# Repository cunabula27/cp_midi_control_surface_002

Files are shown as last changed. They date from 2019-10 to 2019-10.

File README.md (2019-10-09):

# midi_control_surface_002
Midi Control Surface for Arduino Mega 2560 Rev3 running custom OpenDeck firmware available from www.shanteacontrols.com

Well, it's really version 2.1 - I pretty much finished version 2 but made a few rookie errors. Easier to start again with a clean project file.

Once again didn't start on GitHub so no easy way for me to roll the work back #lesigh

I'm learning, just very slowly.

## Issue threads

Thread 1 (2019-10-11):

Potentiometers run backwards

cunabula27, 2019-10-11:
All rotary potentiometers in the prototype boards have reversed polarity so output midi ID 127 at full left and midi ID 0 at full right.

Easily fixed in software using the Configurator and setting the control to Inverted but would be better to fix on the board.

cunabula27, 2019-10-11:
Pin 3 is VCC and Pin 1 is GND on Alps RK09K/RK09D series potentiometers see https://docs-emea.rs-online.com/webdocs/0f4c/0900766b80f4c571.pdf

Closed 2019-10-11.

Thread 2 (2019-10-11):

LED graphics (Presets)

cunabula27, 2019-10-11:
Main board graphics have the number of Presets as 6 - this is the maximum that OpenDeck can have on an Arduino Mega2560. However this project uses the mega6mux target which onlly allows for three presets - it has a lot more available physical controls, there's only so much space on the Arduino's memory.

Adjust board graphics accordingly (or leave blank).

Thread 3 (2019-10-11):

Component graphics (potentiometers)

cunabula27, 2019-10-11:
Having the panel graphics as part of the component footprint works well.

Currently using different potentiometers (same pin placement but wider angle of travel).

Create new footprint to accomodate this.

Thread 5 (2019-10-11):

Library files not correctly linked

cunabula27, 2019-10-11:
Current linking of library files for the project isn't right - rescue.lib is required.

Fix it.

cunabula27, 2019-10-11:
Appears to be a problem with using absolute paths rather than relative ones.

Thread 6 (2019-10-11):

Pin 3 is VCC and Pin 1 is GND on Alps RK09K/RK09D series potentiometers see https://docs-emea.rs-online.com/webdocs/0f4c/0900766b80f4c571.pdf

cunabula27, 2019-10-11:
Pin 3 is VCC and Pin 1 is GND on Alps RK09K/RK09D series potentiometers see https://docs-emea.rs-online.com/webdocs/0f4c/0900766b80f4c571.pdf

_Originally posted by @cunabula27 in https://github.com/cunabula27/cp_midi_control_surface_002/issues/1#issuecomment-541006642_

Reverse symbols in schematic and correctly connect components on board to reflect this.

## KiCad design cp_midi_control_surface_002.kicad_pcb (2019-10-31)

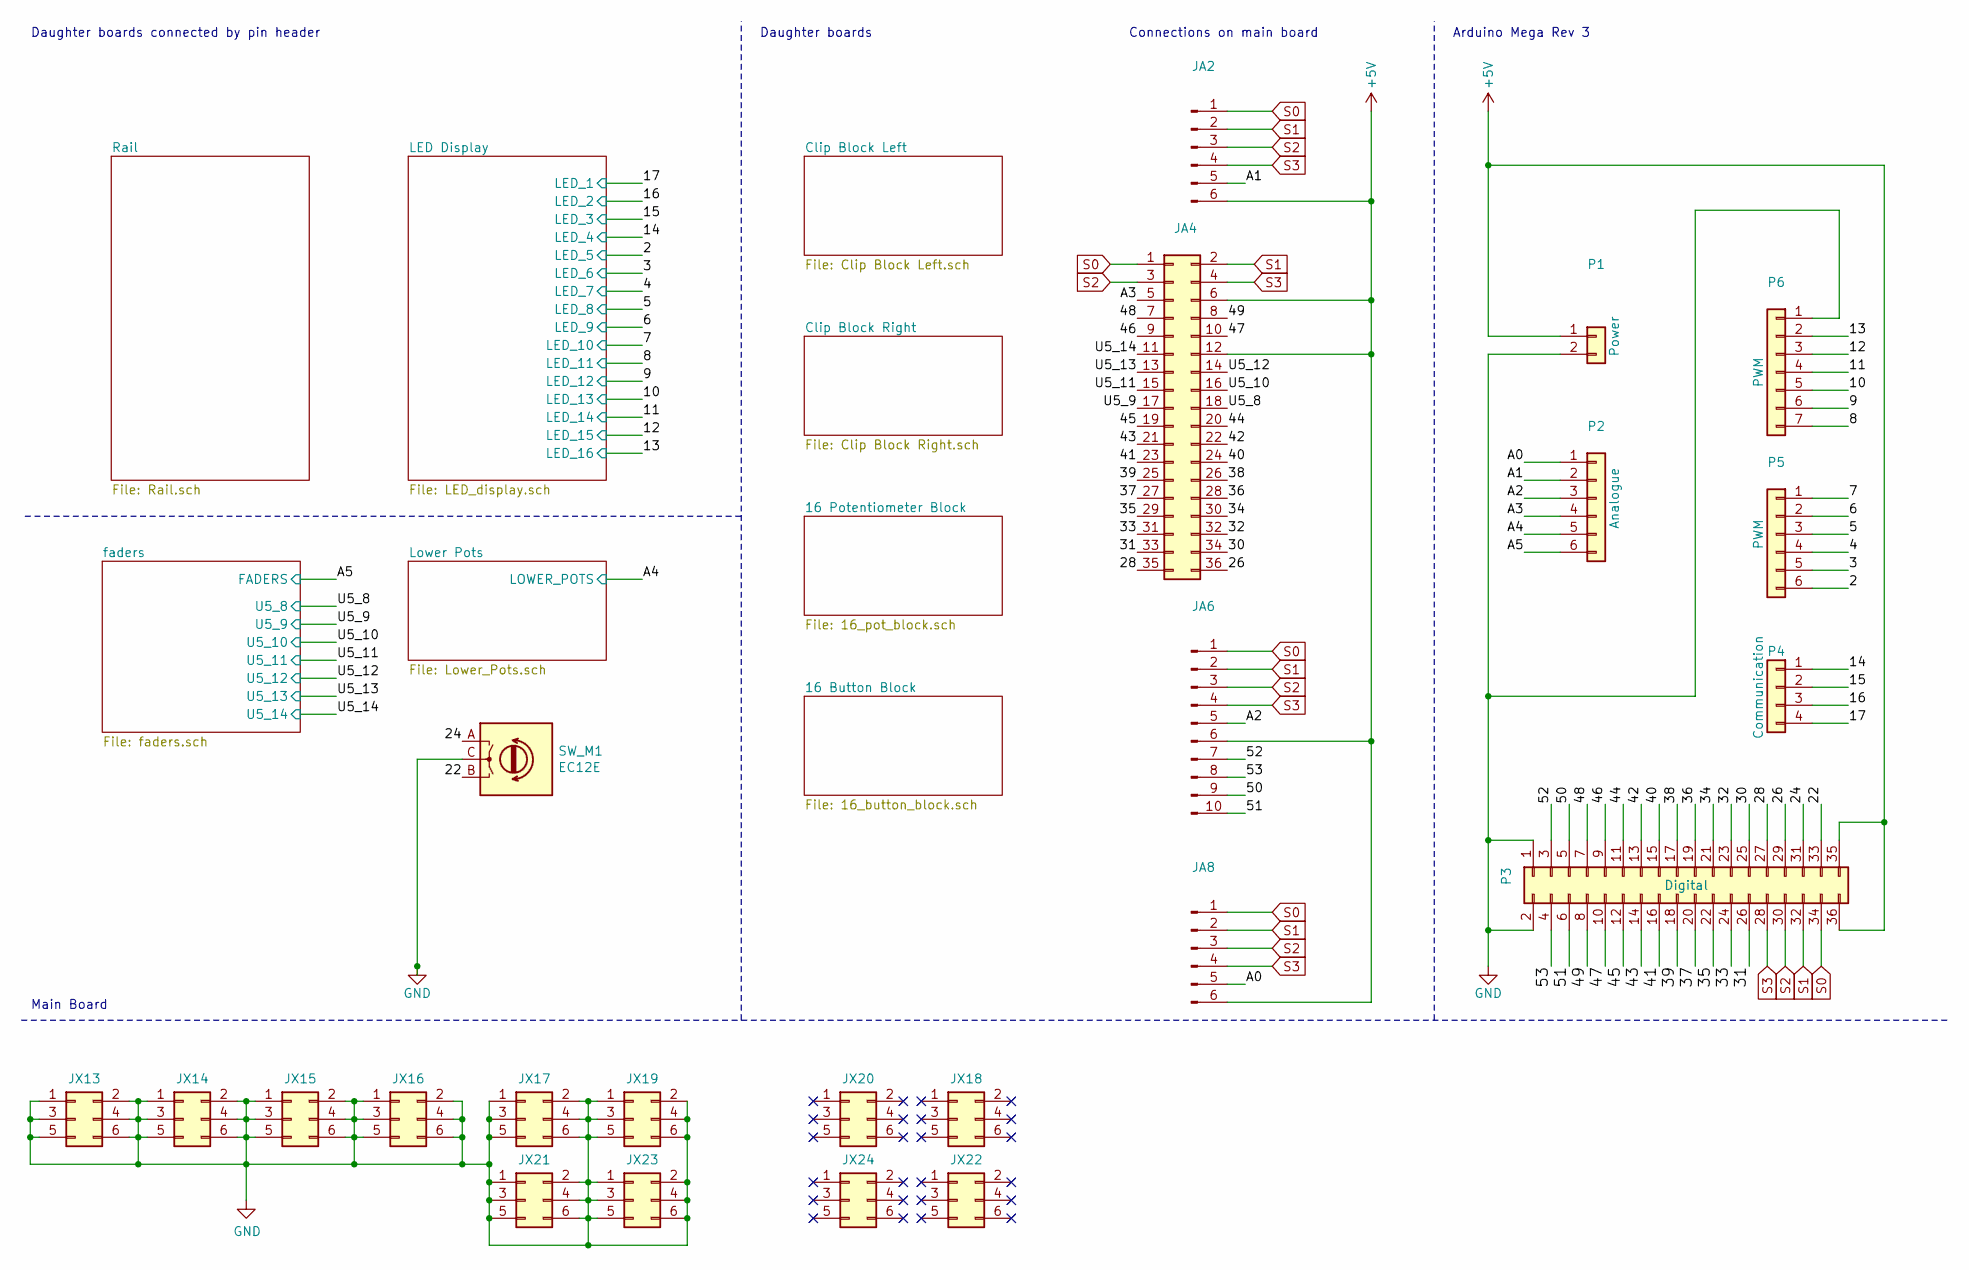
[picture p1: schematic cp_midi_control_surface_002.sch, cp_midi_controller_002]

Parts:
JA2, JA8: PinHeader_2x03_P2.54mm_Vertical
JA4: PinHeader_2x18_P2.54mm_Vertical
JA6: PinHeader_2x05_P2.54mm_Vertical
JX13, JX14, JX15, JX16, JX17, JX18, JX19, JX20, JX21, JX22, JX23, JX24: Conn_02x03_Odd_Even; PinHeader_2x03_P2.54mm_Vertical
P1: Power; PinHeader_1x02_P2.54mm_Vertical
P2: Analogue; PinHeader_1x06_P2.54mm_Vertical
P3: Digital; PinHeader_2x18_P2.54mm_Vertical
P4: Communication; PinHeader_1x04_P2.54mm_Vertical
P5: PWM; PinHeader_1x06_P2.54mm_Vertical
P6: PWM; PinHeader_1x07_P2.54mm_Vertical
SW_M1: EC12E; RotaryEncoder_Alps_EC12E_Vertical_H20mm_6_Preset_Silk_EDIT

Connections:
+5V: JA2.6, JA4.6, JA4.12, JA6.6, JA8.6, P1.1, P3.35, P3.36; also elsewhere on the board
/2: P5.6; also elsewhere on the board
/3: P5.5; also elsewhere on the board
/4: P5.4; also elsewhere on the board
/5: P5.3; also elsewhere on the board
/6: P5.2; also elsewhere on the board
/7: P5.1; also elsewhere on the board
/8: P6.7; also elsewhere on the board
/9: P6.6; also elsewhere on the board
/10: P6.5; also elsewhere on the board
/11: P6.4; also elsewhere on the board
/12: P6.3; also elsewhere on the board
/13: P6.2; also elsewhere on the board
/14: P4.1; also elsewhere on the board
/15: P4.2; also elsewhere on the board
/16: P4.3; also elsewhere on the board
/17: P4.4; also elsewhere on the board
/22: P3.33, SW_M1.B
/24: P3.31, SW_M1.A
/26: JA4.36, P3.29
/28: JA4.35, P3.27
/30: JA4.34, P3.25
/31: JA4.33, P3.26
/32: JA4.32, P3.23
/33: JA4.31, P3.24
/34: JA4.30, P3.21
/35: JA4.29, P3.22
/36: JA4.28, P3.19
/37: JA4.27, P3.20
/38: JA4.26, P3.17
/39: JA4.25, P3.18
/40: JA4.24, P3.15
/41: JA4.23, P3.16
/42: JA4.22, P3.13
/43: JA4.21, P3.14
/44: JA4.20, P3.11
/45: JA4.19, P3.12
/46: JA4.9, P3.9
/47: JA4.10, P3.10
/48: JA4.7, P3.7
/49: JA4.8, P3.8
/50: JA6.9, P3.5
/51: JA6.10, P3.6
/52: JA6.7, P3.3
/53: JA6.8, P3.4
/A0: JA8.5, P2.1
/A1: JA2.5, P2.2
/A2: JA6.5, P2.3
/A3: JA4.5, P2.4
/A4: P2.5; also elsewhere on the board
/A5: P2.6; also elsewhere on the board
/U5_8: JA4.18; also elsewhere on the board
/U5_9: JA4.17; also elsewhere on the board
/U5_10: JA4.16; also elsewhere on the board
/U5_11: JA4.15; also elsewhere on the board
/U5_12: JA4.14; also elsewhere on the board
/U5_13: JA4.13; also elsewhere on the board
/U5_14: JA4.11; also elsewhere on the board
GND: JX13.1, JX13.2, JX13.3, JX13.4, JX13.5, JX13.6, JX14.1, JX14.2, JX14.3, JX14.4, JX14.5, JX14.6, JX15.1, JX15.2, JX15.3, JX15.4, JX15.5, JX15.6, JX16.1, JX16.2, JX16.3, JX16.4, JX16.5, JX16.6, JX17.1, JX17.2, JX17.3, JX17.4, JX17.5, JX17.6, JX19.1, JX19.2, JX19.3, JX19.4, JX19.5, JX19.6, JX21.1, JX21.2, JX21.3, JX21.4, JX21.5, JX21.6, JX23.1, JX23.2, JX23.3, JX23.4, JX23.5, JX23.6, P1.2, P3.1, P3.2, P6.1, SW_M1.C; also elsewhere on the board
S0: JA2.1, JA4.1, JA6.1, JA8.1, P3.34; also elsewhere on the board
S1: JA2.2, JA4.2, JA6.2, JA8.2, P3.32; also elsewhere on the board
S2: JA2.3, JA4.3, JA6.3, JA8.3, P3.30; also elsewhere on the board
S3: JA2.4, JA4.4, JA6.4, JA8.4, P3.28; also elsewhere on the board

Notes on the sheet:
Arduino Mega Rev 3
Daughter boards
Daughter boards connected by pin header
Main Board
Connections on main board

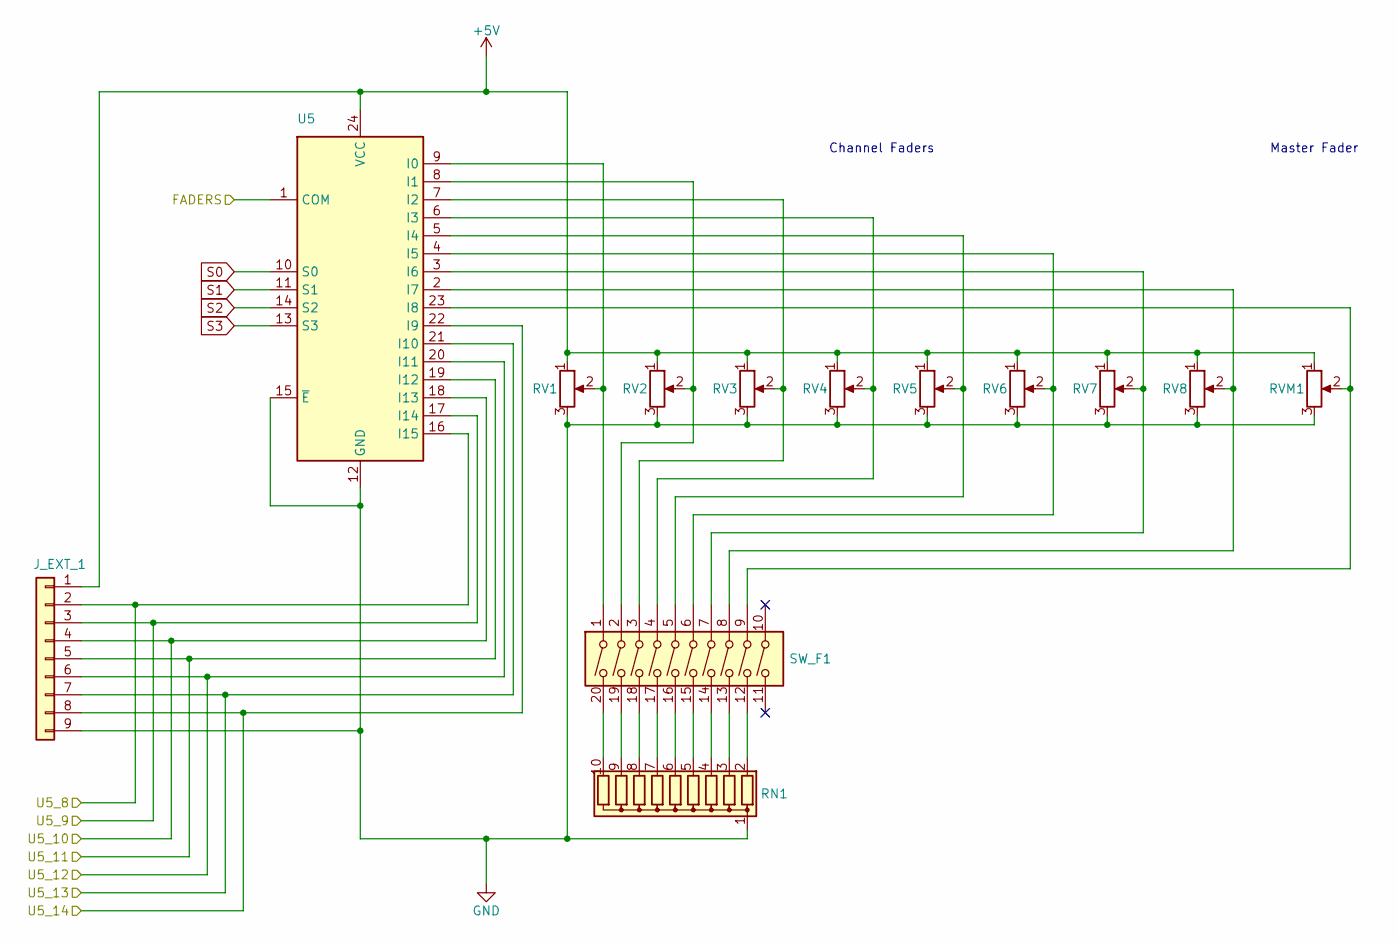
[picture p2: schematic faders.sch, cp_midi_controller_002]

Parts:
J_EXT_1: Conn_01x10; PinSocket_1x09_P2.54mm_Vertical
RN1: 2.2K (Bussed); R_Array_SIP10
RV1, RV2, RV3, RV4, RV5, RV6, RV7, RV8: PTA4543; Potentiometer_Bourns_PTA4543_Single_Slide_CP_EDIT
RVM1: PTA4543; Potentiometer_Bourns_PTA4543_Single_Slide_CP_EDIT
SW_F1: SW_DIP_x10; DIP-20_W7.62mm
U5: CD74HC4067M; SOIC-24W_7.5x15.4mm_P1.27mm

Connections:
+5V: J_EXT_1.1, RV1.1, RV2.1, RV3.1, RV4.1, RV5.1, RV6.1, RV7.1, RV8.1, RVM1.1, U5.24 (VCC); also elsewhere on the board
/A5: U5.1 (COM); also elsewhere on the board
/U5_8: J_EXT_1.2, U5.16 (I15); also elsewhere on the board
/U5_9: J_EXT_1.3, U5.17 (I14); also elsewhere on the board
/U5_10: J_EXT_1.4, U5.18 (I13); also elsewhere on the board
/U5_11: J_EXT_1.5, U5.19 (I12); also elsewhere on the board
/U5_12: J_EXT_1.6, U5.20 (I11); also elsewhere on the board
/U5_13: J_EXT_1.7, U5.21 (I10); also elsewhere on the board
/U5_14: J_EXT_1.8, U5.22 (I9); also elsewhere on the board
GND: J_EXT_1.9, RN1.1 (common), RV1.3, RV2.3, RV3.3, RV4.3, RV5.3, RV6.3, RV7.3, RV8.3, RVM1.3, U5.12 (GND), U5.15 (~E); also elsewhere on the board
unnamed: RN1.2 (R1), SW_F1.12
unnamed: RN1.3 (R2), SW_F1.13
unnamed: RN1.4 (R3), SW_F1.14
unnamed: RN1.5 (R4), SW_F1.15
unnamed: RN1.6 (R5), SW_F1.16
unnamed: RN1.7 (R6), SW_F1.17
unnamed: RN1.8 (R7), SW_F1.18
unnamed: RN1.9 (R8), SW_F1.19
unnamed: RN1.10 (R9), SW_F1.20
unnamed: RV1.2, SW_F1.1, U5.9 (I0)
unnamed: RV2.2, SW_F1.2, U5.8 (I1)
unnamed: RV3.2, SW_F1.3, U5.7 (I2)
unnamed: RV4.2, SW_F1.4, U5.6 (I3)
unnamed: RV5.2, SW_F1.5, U5.5 (I4)
unnamed: RV6.2, SW_F1.6, U5.4 (I5)
unnamed: RV7.2, SW_F1.7, U5.3 (I6)
unnamed: RV8.2, SW_F1.8, U5.2 (I7)
unnamed: RVM1.2, SW_F1.9, U5.23 (I8)
S0: U5.10 (S0); also elsewhere on the board
S1: U5.11 (S1); also elsewhere on the board
S2: U5.14 (S2); also elsewhere on the board
S3: U5.13 (S3); also elsewhere on the board

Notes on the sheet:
Channel Faders
Master Fader

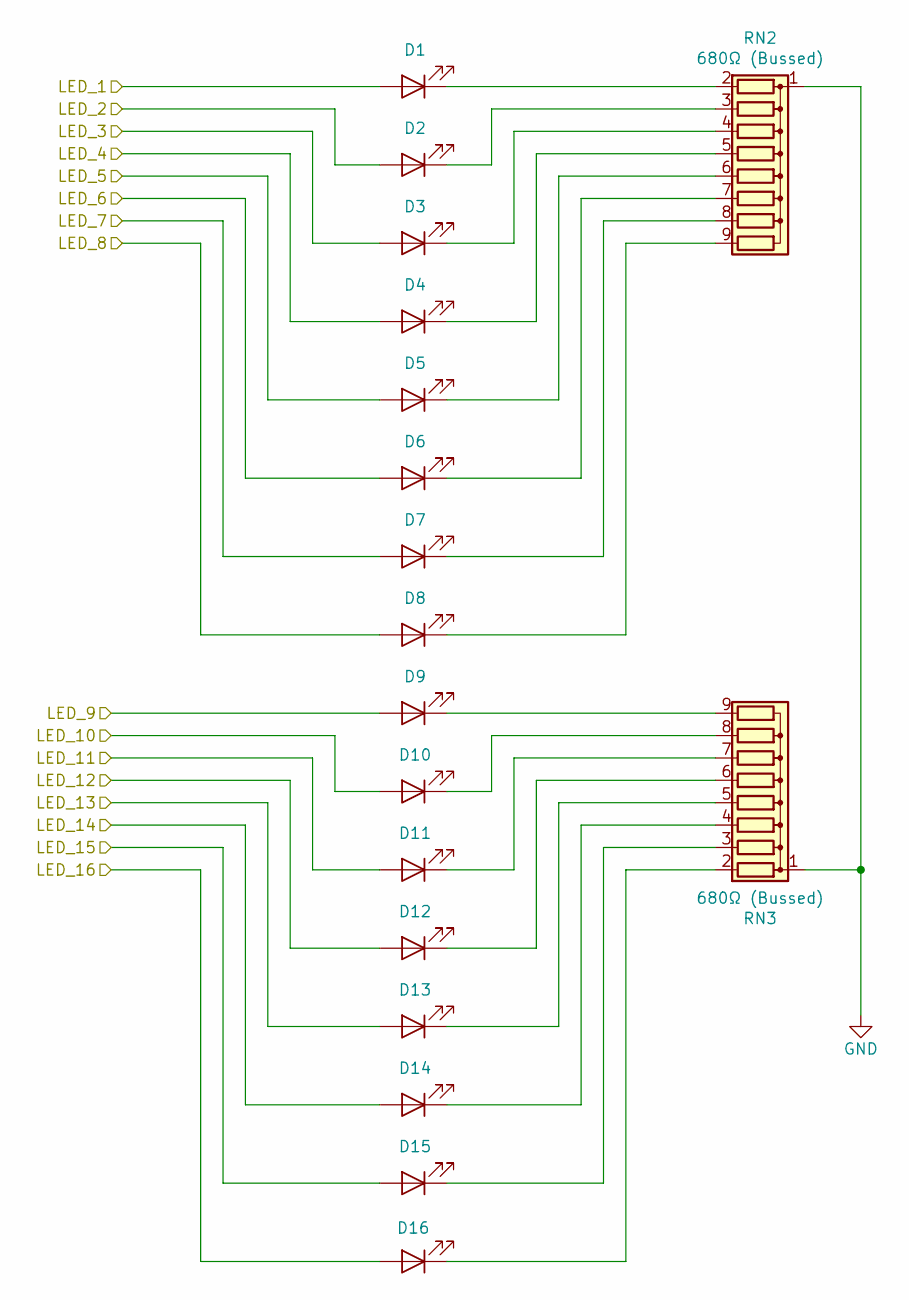
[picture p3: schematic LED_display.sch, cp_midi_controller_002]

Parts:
D1, D2, D3, D4, D5, D6, D7, D8, D9, D10, D11, D12, D13, D14, D15, D16: LED; LED_D3.0mm_EDIT
RN2, RN3: 680Ω (Bussed); R_Array_SIP9

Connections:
/2: D5.2 (A); also elsewhere on the board
/3: D6.2 (A); also elsewhere on the board
/4: D7.2 (A); also elsewhere on the board
/5: D8.2 (A); also elsewhere on the board
/6: D9.2 (A); also elsewhere on the board
/7: D10.2 (A); also elsewhere on the board
/8: D11.2 (A); also elsewhere on the board
/9: D12.2 (A); also elsewhere on the board
/10: D13.2 (A); also elsewhere on the board
/11: D14.2 (A); also elsewhere on the board
/12: D15.2 (A); also elsewhere on the board
/13: D16.2 (A); also elsewhere on the board
/14: D4.2 (A); also elsewhere on the board
/15: D3.2 (A); also elsewhere on the board
/16: D2.2 (A); also elsewhere on the board
/17: D1.2 (A); also elsewhere on the board
GND: RN2.1 (common), RN3.1 (common); also elsewhere on the board
unnamed: D1.1 (K), RN2.2 (R1)
unnamed: D2.1 (K), RN2.3 (R2)
unnamed: D3.1 (K), RN2.4 (R3)
unnamed: D4.1 (K), RN2.5 (R4)
unnamed: D5.1 (K), RN2.6 (R5)
unnamed: D6.1 (K), RN2.7 (R6)
unnamed: D7.1 (K), RN2.8 (R7)
unnamed: D8.1 (K), RN2.9 (R8)
unnamed: D9.1 (K), RN3.9 (R8)
unnamed: D10.1 (K), RN3.8 (R7)
unnamed: D11.1 (K), RN3.7 (R6)
unnamed: D12.1 (K), RN3.6 (R5)
unnamed: D13.1 (K), RN3.5 (R4)
unnamed: D14.1 (K), RN3.4 (R3)
unnamed: D15.1 (K), RN3.3 (R2)
unnamed: D16.1 (K), RN3.2 (R1)

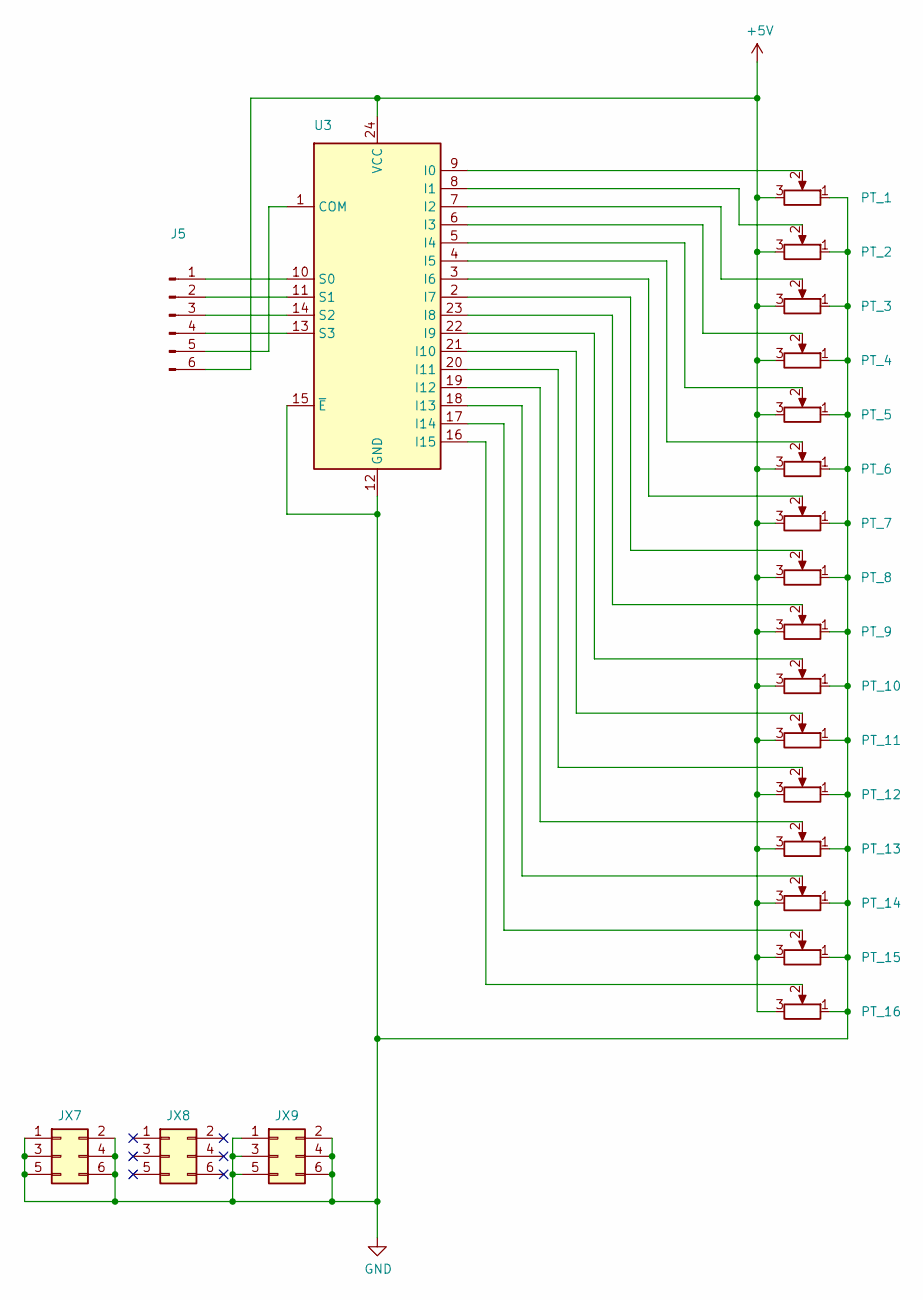
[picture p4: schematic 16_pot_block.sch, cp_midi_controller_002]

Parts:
J5: PinHeader_2x03_P2.54mm_Vertical
JX7, JX8, JX9: Conn_02x03_Odd_Even; PinHeader_2x03_P2.54mm_Vertical
PT_1, PT_2, PT_3, PT_4, PT_5, PT_6, PT_7, PT_8, PT_9, PT_10, PT_11, PT_12, PT_13, PT_14, PT_15, PT_16: 10k; Potentiometer_Alps_RK09D1130X
U3: CD74HC4067M; SOIC-24W_7.5x15.4mm_P1.27mm

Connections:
+5V: J5.6, PT_1.3, PT_2.3, PT_3.3, PT_4.3, PT_5.3, PT_6.3, PT_7.3, PT_8.3, PT_9.3, PT_10.3, PT_11.3, PT_12.3, PT_13.3, PT_14.3, PT_15.3, PT_16.3, U3.24 (VCC); also elsewhere on the board
GND: JX7.1, JX7.2, JX7.3, JX7.4, JX7.5, JX7.6, JX9.1, JX9.2, JX9.3, JX9.4, JX9.5, JX9.6, PT_1.1, PT_2.1, PT_3.1, PT_4.1, PT_5.1, PT_6.1, PT_7.1, PT_8.1, PT_9.1, PT_10.1, PT_11.1, PT_12.1, PT_13.1, PT_14.1, PT_15.1, PT_16.1, U3.12 (GND), U3.15 (~E); also elsewhere on the board
unnamed: J5.1, U3.10 (S0)
unnamed: J5.2, U3.11 (S1)
unnamed: J5.3, U3.14 (S2)
unnamed: J5.4, U3.13 (S3)
unnamed: J5.5, U3.1 (COM)
unnamed: PT_1.2, U3.9 (I0)
unnamed: PT_2.2, U3.8 (I1)
unnamed: PT_3.2, U3.7 (I2)
unnamed: PT_4.2, U3.6 (I3)
unnamed: PT_5.2, U3.5 (I4)
unnamed: PT_6.2, U3.4 (I5)
unnamed: PT_7.2, U3.3 (I6)
unnamed: PT_8.2, U3.2 (I7)
unnamed: PT_9.2, U3.23 (I8)
unnamed: PT_10.2, U3.22 (I9)
unnamed: PT_11.2, U3.21 (I10)
unnamed: PT_12.2, U3.20 (I11)
unnamed: PT_13.2, U3.19 (I12)
unnamed: PT_14.2, U3.18 (I13)
unnamed: PT_15.2, U3.17 (I14)
unnamed: PT_16.2, U3.16 (I15)

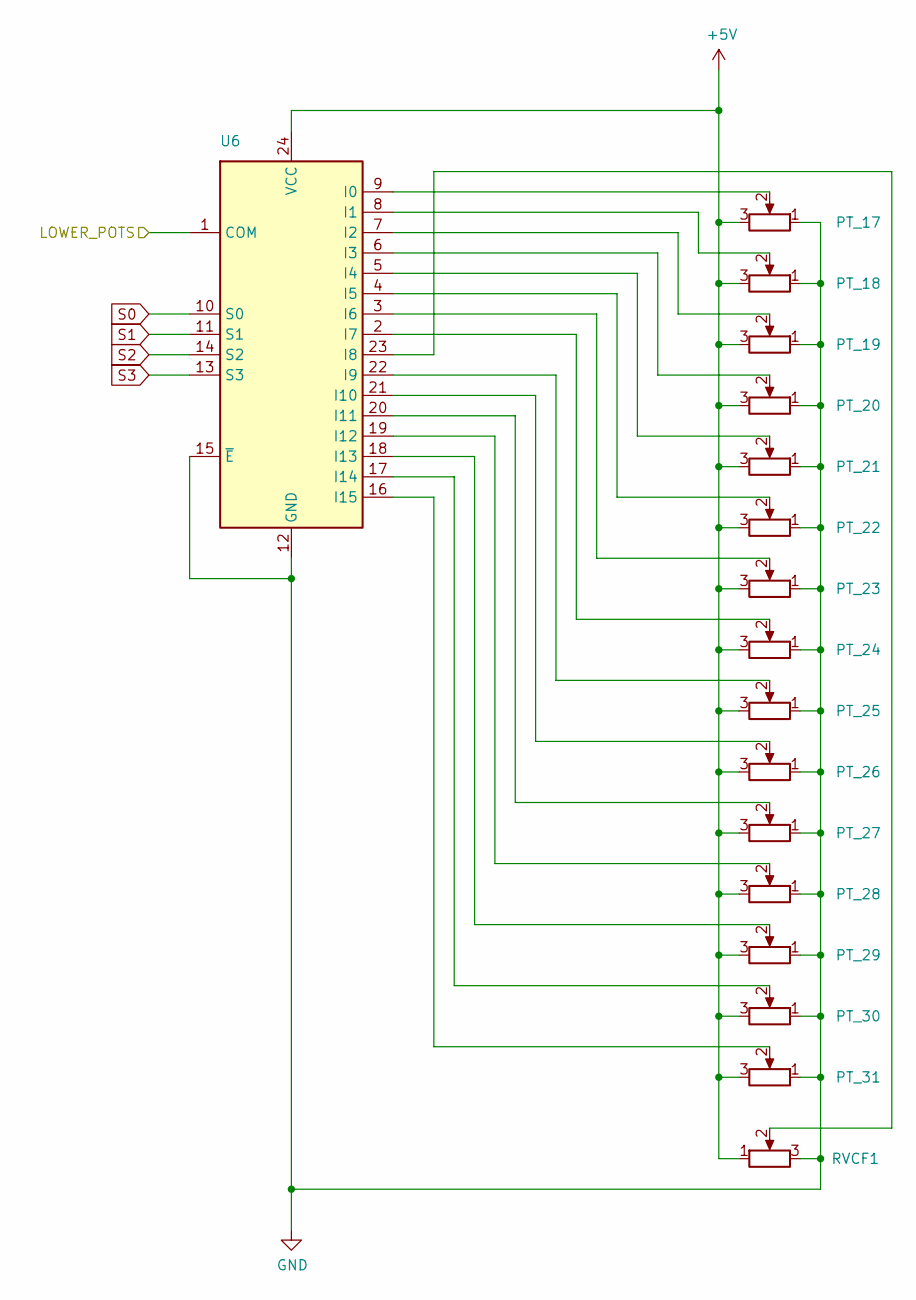
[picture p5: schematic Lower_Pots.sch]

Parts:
PT_17, PT_18, PT_19, PT_20, PT_21, PT_22, PT_23, PT_24, PT_25, PT_26, PT_27, PT_28, PT_29, PT_30, PT_31: 10k; Potentiometer_Alps_RK09D1130X
RVCF1: PTA4543; Potentiometer_Bourns_PTA4543_Single_Slide_CP_EDIT
U6: CD74HC4067M; SOIC-24W_7.5x15.4mm_P1.27mm

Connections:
+5V: PT_17.3, PT_18.3, PT_19.3, PT_20.3, PT_21.3, PT_22.3, PT_23.3, PT_24.3, PT_25.3, PT_26.3, PT_27.3, PT_28.3, PT_29.3, PT_30.3, PT_31.3, RVCF1.1, U6.24 (VCC); also elsewhere on the board
/A4: U6.1 (COM); also elsewhere on the board
GND: PT_17.1, PT_18.1, PT_19.1, PT_20.1, PT_21.1, PT_22.1, PT_23.1, PT_24.1, PT_25.1, PT_26.1, PT_27.1, PT_28.1, PT_29.1, PT_30.1, PT_31.1, RVCF1.3, U6.12 (GND), U6.15 (~E); also elsewhere on the board
unnamed: PT_17.2, U6.9 (I0)
unnamed: PT_18.2, U6.8 (I1)
unnamed: PT_19.2, U6.7 (I2)
unnamed: PT_20.2, U6.6 (I3)
unnamed: PT_21.2, U6.5 (I4)
unnamed: PT_22.2, U6.4 (I5)
unnamed: PT_23.2, U6.3 (I6)
unnamed: PT_24.2, U6.2 (I7)
unnamed: PT_25.2, U6.22 (I9)
unnamed: PT_26.2, U6.21 (I10)
unnamed: PT_27.2, U6.20 (I11)
unnamed: PT_28.2, U6.19 (I12)
unnamed: PT_29.2, U6.18 (I13)
unnamed: PT_30.2, U6.17 (I14)
unnamed: PT_31.2, U6.16 (I15)
unnamed: RVCF1.2, U6.23 (I8)
S0: U6.10 (S0); also elsewhere on the board
S1: U6.11 (S1); also elsewhere on the board
S2: U6.14 (S2); also elsewhere on the board
S3: U6.13 (S3); also elsewhere on the board

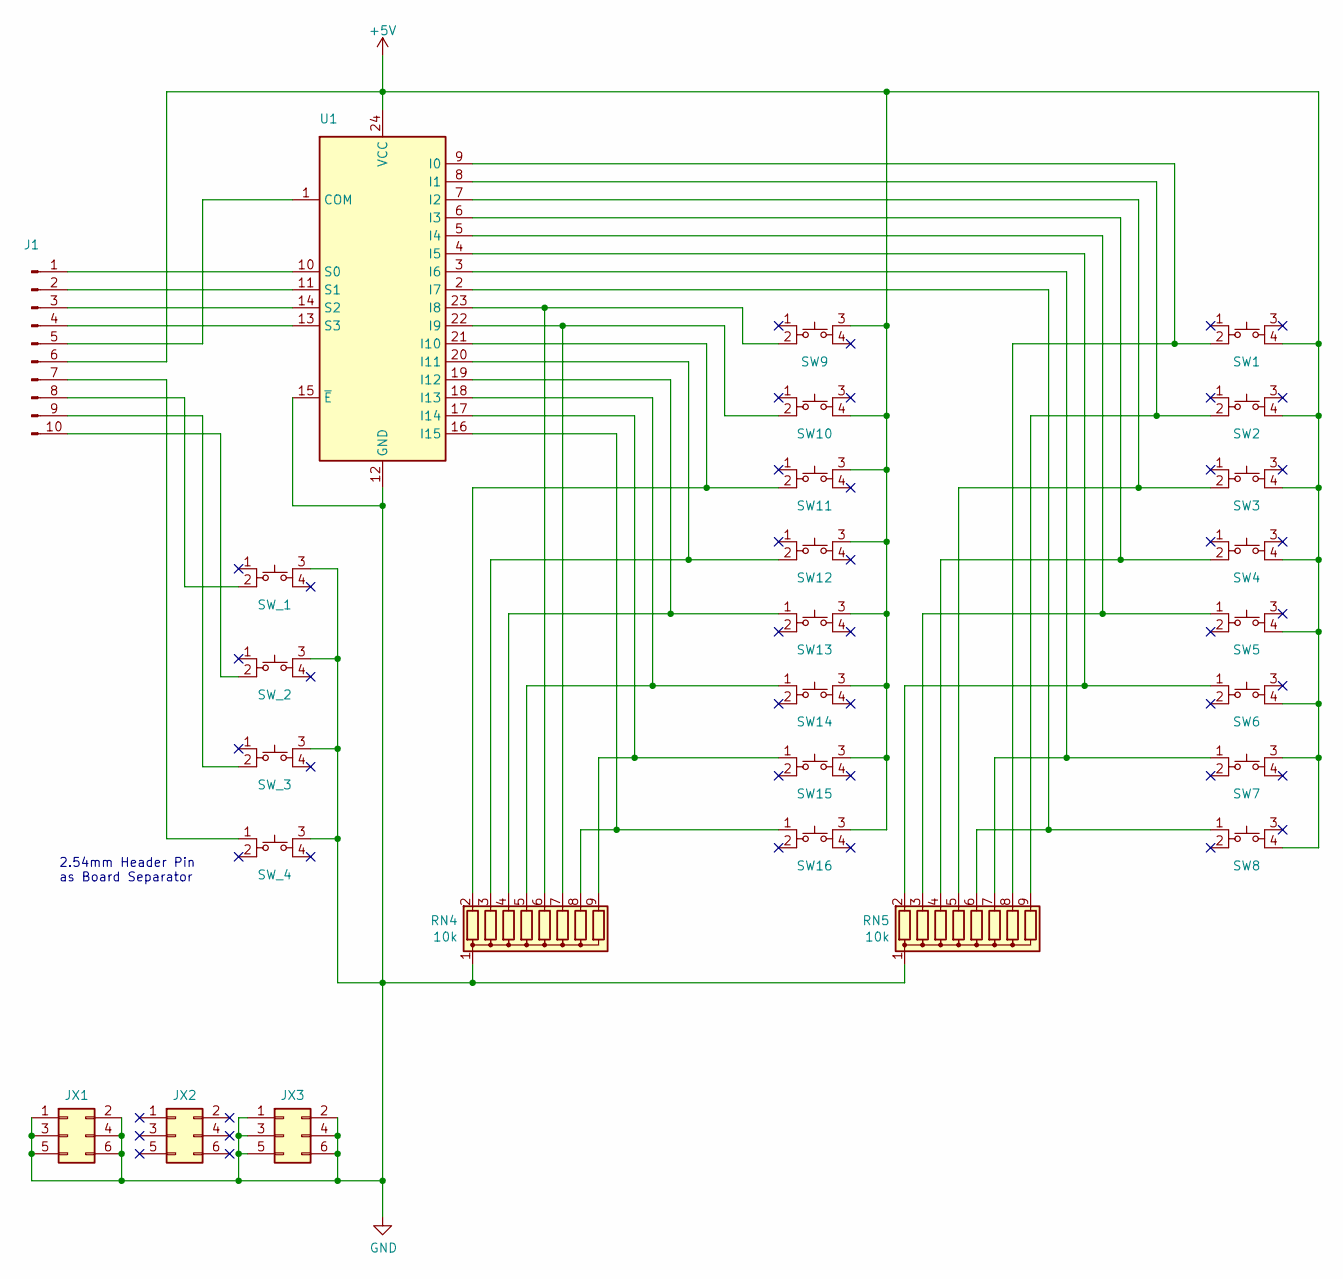
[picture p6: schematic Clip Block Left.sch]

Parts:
J1: Conn_02x05_Odd_Even; PinHeader_2x05_P2.54mm_Vertical
JX1, JX2, JX3: Conn_02x03_Odd_Even; PinHeader_2x03_P2.54mm_Vertical
RN4, RN5: 10k; R_Array_SIP9
SW1, SW2, SW3, SW4, SW5, SW6, SW7, SW8, SW9, SW10, SW11, SW12, SW13, SW14, SW15, SW16: B3F-5050; Omron_B3F-5050
SW_1, SW_2, SW_3, SW_4: B3F-5050; Omron_B3F-5050
U1: CD74HC4067M; SOIC-24W_7.5x15.4mm_P1.27mm

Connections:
+5V: J1.6, SW1.4, SW2.4, SW3.4, SW4.4, SW5.4, SW6.4, SW7.3, SW8.4, SW9.3, SW10.4, SW11.3, SW12.3, SW13.3, SW14.3, SW15.3, SW16.3, U1.24 (VCC); also elsewhere on the board
GND: JX1.1, JX1.2, JX1.3, JX1.4, JX1.5, JX1.6, JX3.1, JX3.2, JX3.3, JX3.4, JX3.5, JX3.6, RN4.1 (common), RN5.1 (common), SW_1.3, SW_2.3, SW_3.3, SW_4.3, U1.12 (GND), U1.15 (~E); also elsewhere on the board
unnamed: J1.1, U1.10 (S0)
unnamed: J1.2, U1.11 (S1)
unnamed: J1.3, U1.14 (S2)
unnamed: J1.4, U1.13 (S3)
unnamed: J1.5, U1.1 (COM)
unnamed: J1.7, SW_4.1 (A)
unnamed: J1.8, SW_1.2
unnamed: J1.9, SW_3.2
unnamed: J1.10, SW_2.2
unnamed: RN4.2 (R1), SW11.2, U1.21 (I10)
unnamed: RN4.3 (R2), SW12.2, U1.20 (I11)
unnamed: RN4.4 (R3), SW13.1 (A), U1.19 (I12)
unnamed: RN4.5 (R4), SW14.1 (A), U1.18 (I13)
unnamed: RN4.6 (R5), SW9.2, U1.23 (I8)
unnamed: RN4.7 (R6), SW10.2, U1.22 (I9)
unnamed: RN4.8 (R7), SW16.1 (A), U1.16 (I15)
unnamed: RN4.9 (R8), SW15.1 (A), U1.17 (I14)
unnamed: RN5.2 (R1), SW6.1 (A), U1.4 (I5)
unnamed: RN5.3 (R2), SW5.1 (A), U1.5 (I4)
unnamed: RN5.4 (R3), SW4.2, U1.6 (I3)
unnamed: RN5.5 (R4), SW3.2, U1.7 (I2)
unnamed: RN5.6 (R5), SW8.1 (A), U1.2 (I7)
unnamed: RN5.7 (R6), SW7.1 (A), U1.3 (I6)
unnamed: RN5.8 (R7), SW1.2, U1.9 (I0)
unnamed: RN5.9 (R8), SW2.2, U1.8 (I1)

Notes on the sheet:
2.54mm Header Pin as Board Separator

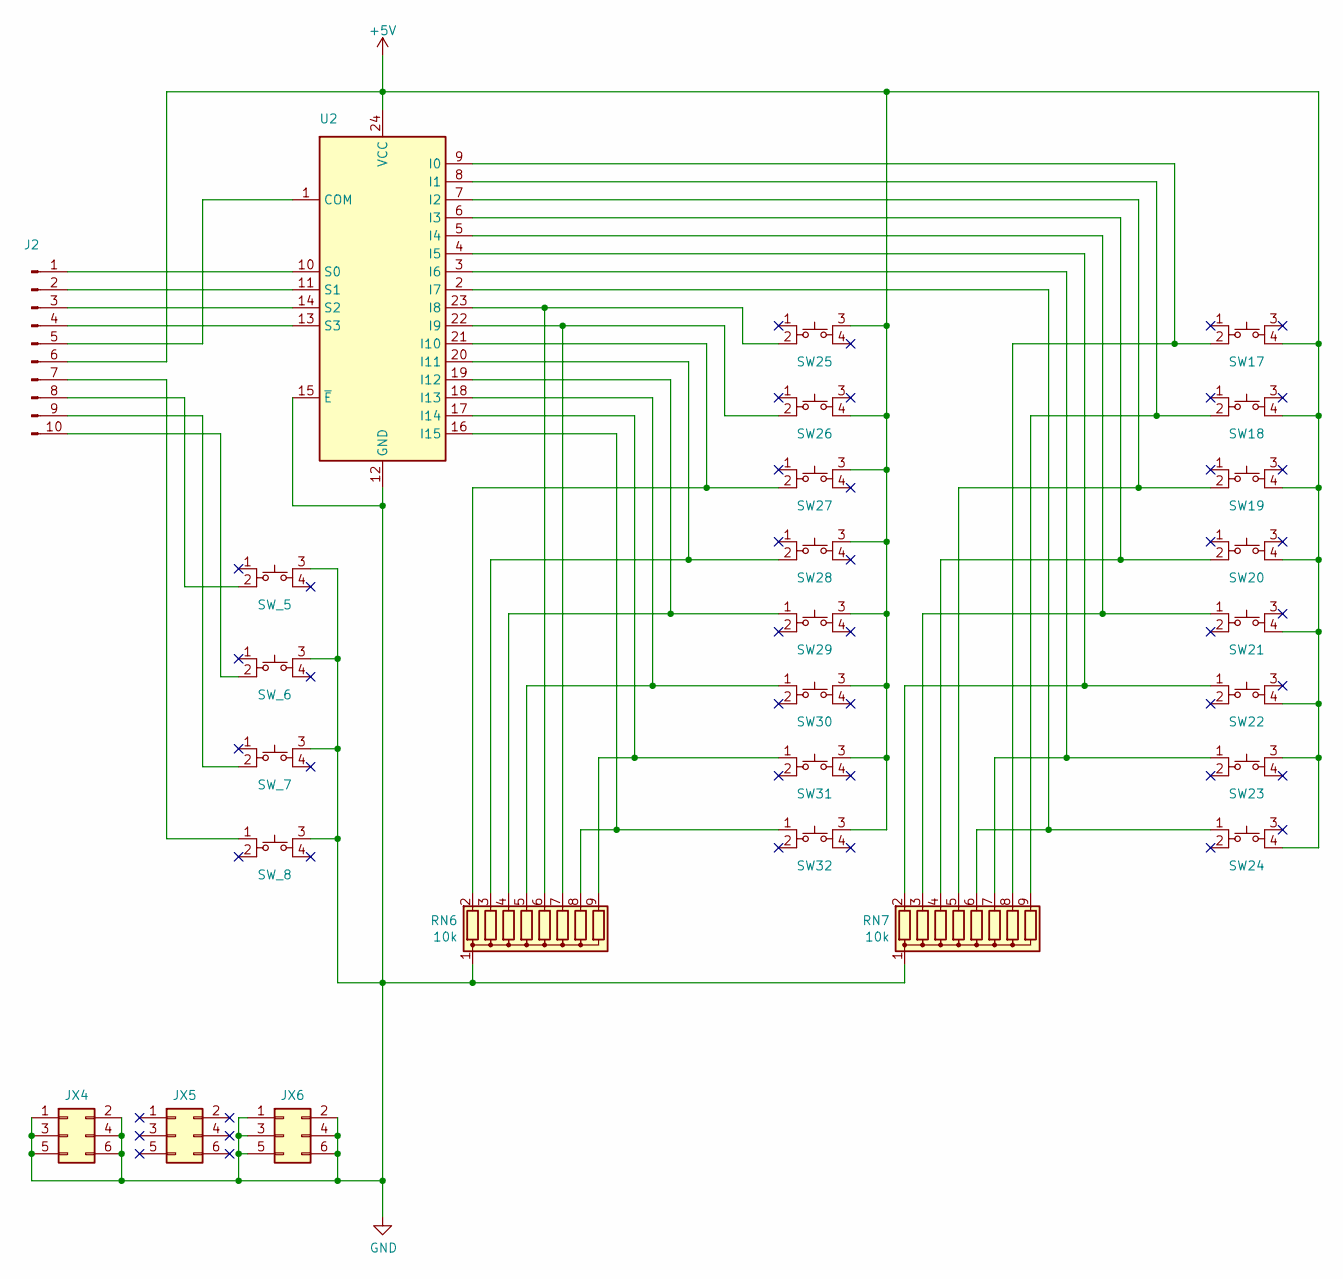
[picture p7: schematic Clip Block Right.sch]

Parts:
J2: Conn_02x05_Odd_Even; PinHeader_2x05_P2.54mm_Vertical
JX4, JX5, JX6: Conn_02x03_Odd_Even; PinHeader_2x03_P2.54mm_Vertical
RN6, RN7: 10k; R_Array_SIP9
SW17, SW18, SW19, SW20, SW21, SW22, SW23, SW24, SW25, SW26, SW27, SW28, SW29, SW30, SW31, SW32: B3F-5050; Omron_B3F-5050
SW_5, SW_6, SW_7, SW_8: B3F-5050; Omron_B3F-5050
U2: CD74HC4067M; SOIC-24W_7.5x15.4mm_P1.27mm

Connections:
+5V: J2.6, SW17.4, SW18.4, SW19.4, SW20.4, SW21.4, SW22.4, SW23.3, SW24.4, SW25.3, SW26.4, SW27.3, SW28.3, SW29.3, SW30.3, SW31.3, SW32.3, U2.24 (VCC); also elsewhere on the board
GND: JX4.1, JX4.2, JX4.3, JX4.4, JX4.5, JX4.6, JX6.1, JX6.2, JX6.3, JX6.4, JX6.5, JX6.6, RN6.1 (common), RN7.1 (common), SW_5.3, SW_6.3, SW_7.3, SW_8.3, U2.12 (GND), U2.15 (~E); also elsewhere on the board
unnamed: J2.1, U2.10 (S0)
unnamed: J2.2, U2.11 (S1)
unnamed: J2.3, U2.14 (S2)
unnamed: J2.4, U2.13 (S3)
unnamed: J2.5, U2.1 (COM)
unnamed: J2.7, SW_8.1 (A)
unnamed: J2.8, SW_5.2
unnamed: J2.9, SW_7.2
unnamed: J2.10, SW_6.2
unnamed: RN6.2 (R1), SW27.2, U2.21 (I10)
unnamed: RN6.3 (R2), SW28.2, U2.20 (I11)
unnamed: RN6.4 (R3), SW29.1 (A), U2.19 (I12)
unnamed: RN6.5 (R4), SW30.1 (A), U2.18 (I13)
unnamed: RN6.6 (R5), SW25.2, U2.23 (I8)
unnamed: RN6.7 (R6), SW26.2, U2.22 (I9)
unnamed: RN6.8 (R7), SW32.1 (A), U2.16 (I15)
unnamed: RN6.9 (R8), SW31.1 (A), U2.17 (I14)
unnamed: RN7.2 (R1), SW22.1 (A), U2.4 (I5)
unnamed: RN7.3 (R2), SW21.1 (A), U2.5 (I4)
unnamed: RN7.4 (R3), SW20.2, U2.6 (I3)
unnamed: RN7.5 (R4), SW19.2, U2.7 (I2)
unnamed: RN7.6 (R5), SW24.1 (A), U2.2 (I7)
unnamed: RN7.7 (R6), SW23.1 (A), U2.3 (I6)
unnamed: RN7.8 (R7), SW17.2, U2.9 (I0)
unnamed: RN7.9 (R8), SW18.2, U2.8 (I1)

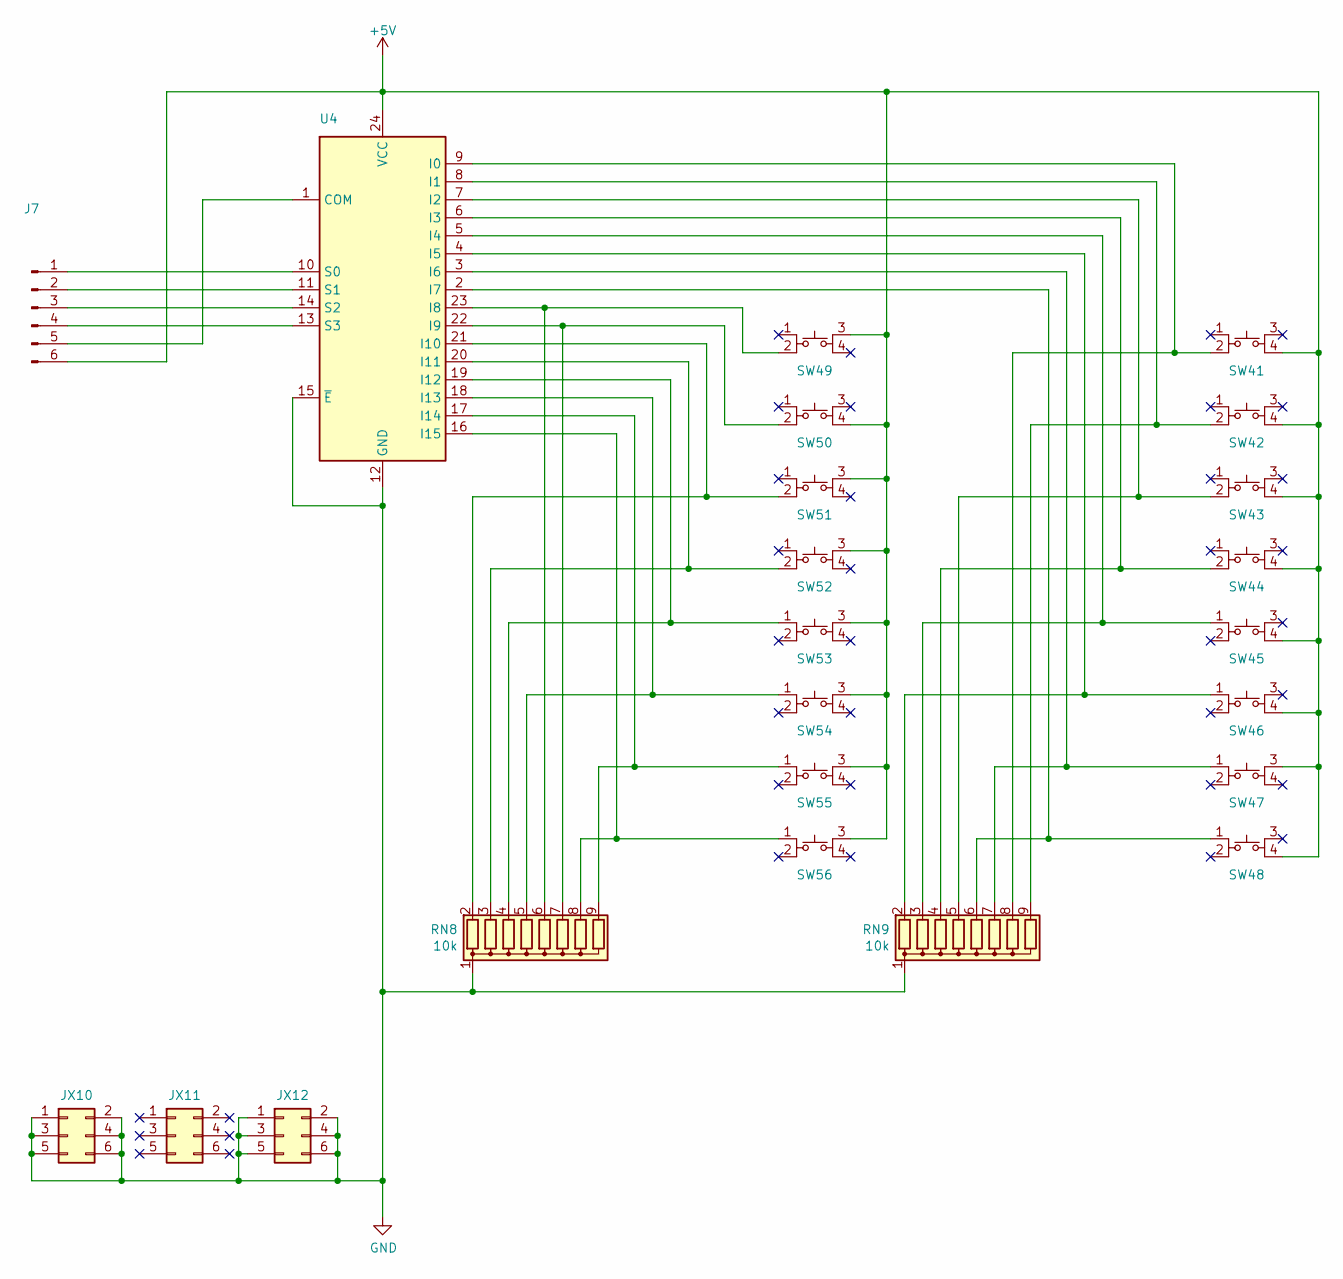
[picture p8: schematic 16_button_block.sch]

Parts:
J7: Conn_02x05_Odd_Even; PinHeader_2x03_P2.54mm_Vertical
JX10, JX11, JX12: Conn_02x03_Odd_Even; PinHeader_2x03_P2.54mm_Vertical
RN8, RN9: 10k; R_Array_SIP9
SW41, SW42, SW43, SW44, SW45, SW46, SW47, SW48, SW49, SW50, SW51, SW52, SW53, SW54, SW55, SW56: B3F-5050; Omron_B3F-5050
U4: CD74HC4067M; SOIC-24W_7.5x15.4mm_P1.27mm

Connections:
+5V: J7.6, SW41.4, SW42.4, SW43.4, SW44.4, SW45.4, SW46.4, SW47.3, SW48.4, SW49.3, SW50.4, SW51.3, SW52.3, SW53.3, SW54.3, SW55.3, SW56.3, U4.24 (VCC); also elsewhere on the board
GND: JX10.1, JX10.2, JX10.3, JX10.4, JX10.5, JX10.6, JX12.1, JX12.2, JX12.3, JX12.4, JX12.5, JX12.6, RN8.1 (common), RN9.1 (common), U4.12 (GND), U4.15 (~E); also elsewhere on the board
unnamed: J7.1, U4.10 (S0)
unnamed: J7.2, U4.11 (S1)
unnamed: J7.3, U4.14 (S2)
unnamed: J7.4, U4.13 (S3)
unnamed: J7.5, U4.1 (COM)
unnamed: RN8.2 (R1), SW51.2, U4.21 (I10)
unnamed: RN8.3 (R2), SW52.2, U4.20 (I11)
unnamed: RN8.4 (R3), SW53.1 (A), U4.19 (I12)
unnamed: RN8.5 (R4), SW54.1 (A), U4.18 (I13)
unnamed: RN8.6 (R5), SW49.2, U4.23 (I8)
unnamed: RN8.7 (R6), SW50.2, U4.22 (I9)
unnamed: RN8.8 (R7), SW56.1 (A), U4.16 (I15)
unnamed: RN8.9 (R8), SW55.1 (A), U4.17 (I14)
unnamed: RN9.2 (R1), SW46.1 (A), U4.4 (I5)
unnamed: RN9.3 (R2), SW45.1 (A), U4.5 (I4)
unnamed: RN9.4 (R3), SW44.2, U4.6 (I3)
unnamed: RN9.5 (R4), SW43.2, U4.7 (I2)
unnamed: RN9.6 (R5), SW48.1 (A), U4.2 (I7)
unnamed: RN9.7 (R6), SW47.1 (A), U4.3 (I6)
unnamed: RN9.8 (R7), SW41.2, U4.9 (I0)
unnamed: RN9.9 (R8), SW42.2, U4.8 (I1)

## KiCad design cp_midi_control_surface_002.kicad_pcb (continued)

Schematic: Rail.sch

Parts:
J3, J6, J9, J11, J13, J15, J17: Conn_01x38_Male; PinSocket_2x19_P2.54mm_Vertical
J4, J8, J10, J12, J14, J16, J18: Conn_01x38_Female; PinSocket_2x19_P2.54mm_Vertical
J19: Conn_01x18_Male; PinSocket_2x09_P2.54mm_Vertical
J20: Conn_01x18_Female; PinSocket_2x09_P2.54mm_Vertical
J21, J22, J23, J24, J25, J26, J27, J28: Conn_01x01_MountingPin; MountingHole_3.2mm_M3_ISO14580_Pad

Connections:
GND: J6.17, J6.18, J6.19, J6.20, J6.21, J6.22, J8.17, J8.18, J8.19, J8.20, J8.21, J8.22, J11.17, J11.18, J11.19, J11.20, J11.21, J11.22, J12.17, J12.18, J12.19, J12.20, J12.21, J12.22, J15.17, J15.18, J15.19, J15.20, J15.21, J15.22, J16.17, J16.18, J16.19, J16.20, J16.21, J16.22, J19.1, J19.2, J19.3, J19.4, J19.5, J19.6, J19.17, J19.18, J20.1, J20.2, J20.3, J20.4, J20.5, J20.6, J20.17, J20.18, J21.1, J22.1, J23.1, J24.1, J25.1, J26.1, J27.1, J28.1; also elsewhere on the board
unnamed: J3.1, J4.1
unnamed: J3.2, J4.2
unnamed: J3.3, J4.3
unnamed: J3.4, J4.4
unnamed: J3.5, J4.5
unnamed: J3.6, J4.6
unnamed: J3.7, J4.7
unnamed: J3.8, J4.8
unnamed: J3.9, J4.9
unnamed: J3.10, J4.10
unnamed: J3.11, J4.11
unnamed: J3.12, J4.12
unnamed: J3.13, J4.13
unnamed: J3.14, J4.14
unnamed: J3.15, J4.15
unnamed: J3.16, J4.16
unnamed: J3.17, J4.17
unnamed: J3.18, J4.18
unnamed: J3.19, J4.19
unnamed: J3.20, J4.20
unnamed: J3.21, J4.21
unnamed: J3.22, J4.22
unnamed: J3.23, J4.23
unnamed: J3.24, J4.24
unnamed: J3.25, J4.25
unnamed: J3.26, J4.26
unnamed: J3.27, J4.27
unnamed: J3.28, J4.28
unnamed: J3.29, J4.29
unnamed: J3.30, J4.30
unnamed: J3.31, J4.31
unnamed: J3.32, J4.32
unnamed: J3.33, J4.33
unnamed: J3.34, J4.34
unnamed: J3.35, J4.35
unnamed: J3.36, J4.36
unnamed: J3.37, J4.37
unnamed: J3.38, J4.38
unnamed: J6.1, J8.1
unnamed: J6.2, J8.2
unnamed: J6.3, J8.3
unnamed: J6.4, J8.4
unnamed: J6.5, J8.5
unnamed: J6.6, J8.6
unnamed: J6.7, J8.7
unnamed: J6.8, J8.8
unnamed: J6.9, J8.9
unnamed: J6.10, J8.10
unnamed: J6.11, J8.11
unnamed: J6.12, J8.12
unnamed: J6.13, J8.13
unnamed: J6.14, J8.14
unnamed: J6.15, J8.15
unnamed: J6.16, J8.16
unnamed: J6.23, J8.23
unnamed: J6.24, J8.24
unnamed: J6.25, J8.25
unnamed: J6.26, J8.26
unnamed: J6.27, J8.27
unnamed: J6.28, J8.28
unnamed: J6.29, J8.29
unnamed: J6.30, J8.30
unnamed: J6.31, J8.31
unnamed: J6.32, J8.32
unnamed: J6.33, J8.33
unnamed: J6.34, J8.34
unnamed: J6.35, J8.35
unnamed: J6.36, J8.36
unnamed: J6.37, J8.37
unnamed: J6.38, J8.38
unnamed: J9.1, J10.1
unnamed: J9.2, J10.2
unnamed: J9.3, J10.3
unnamed: J9.4, J10.4
unnamed: J9.5, J10.5
unnamed: J9.6, J10.6
unnamed: J9.7, J10.7
unnamed: J9.8, J10.8
unnamed: J9.9, J10.9
unnamed: J9.10, J10.10
unnamed: J9.11, J10.11
unnamed: J9.12, J10.12
unnamed: J9.13, J10.13
unnamed: J9.14, J10.14
unnamed: J9.15, J10.15
unnamed: J9.16, J10.16
unnamed: J9.17, J10.17
unnamed: J9.18, J10.18
unnamed: J9.19, J10.19
unnamed: J9.20, J10.20
unnamed: J9.21, J10.21
unnamed: J9.22, J10.22
unnamed: J9.23, J10.23
unnamed: J9.24, J10.24
unnamed: J9.25, J10.25
unnamed: J9.26, J10.26
unnamed: J9.27, J10.27
unnamed: J9.28, J10.28
unnamed: J9.29, J10.29
unnamed: J9.30, J10.30
unnamed: J9.31, J10.31
unnamed: J9.32, J10.32
unnamed: J9.33, J10.33
unnamed: J9.34, J10.34
unnamed: J9.35, J10.35
unnamed: J9.36, J10.36
unnamed: J9.37, J10.37
unnamed: J9.38, J10.38
unnamed: J11.1, J12.1
unnamed: J11.2, J12.2
unnamed: J11.3, J12.3
unnamed: J11.4, J12.4
unnamed: J11.5, J12.5
unnamed: J11.6, J12.6
unnamed: J11.7, J12.7
unnamed: J11.8, J12.8
unnamed: J11.9, J12.9
unnamed: J11.10, J12.10
unnamed: J11.11, J12.11
unnamed: J11.12, J12.12
unnamed: J11.13, J12.13
unnamed: J11.14, J12.14
unnamed: J11.15, J12.15
unnamed: J11.16, J12.16
unnamed: J11.23, J12.23
unnamed: J11.24, J12.24
unnamed: J11.25, J12.25
unnamed: J11.26, J12.26
unnamed: J11.27, J12.27
unnamed: J11.28, J12.28
unnamed: J11.29, J12.29
unnamed: J11.30, J12.30
unnamed: J11.31, J12.31
unnamed: J11.32, J12.32
unnamed: J11.33, J12.33
unnamed: J11.34, J12.34
unnamed: J11.35, J12.35
unnamed: J11.36, J12.36
unnamed: J11.37, J12.37
unnamed: J11.38, J12.38
unnamed: J13.1, J14.1
unnamed: J13.2, J14.2
unnamed: J13.3, J14.3
unnamed: J13.4, J14.4
unnamed: J13.5, J14.5
unnamed: J13.6, J14.6
unnamed: J13.7, J14.7
unnamed: J13.8, J14.8
unnamed: J13.9, J14.9
unnamed: J13.10, J14.10
unnamed: J13.11, J14.11
unnamed: J13.12, J14.12
unnamed: J13.13, J14.13
unnamed: J13.14, J14.14
unnamed: J13.15, J14.15
unnamed: J13.16, J14.16
unnamed: J13.17, J14.17
unnamed: J13.18, J14.18
unnamed: J13.19, J14.19
unnamed: J13.20, J14.20
unnamed: J13.21, J14.21
unnamed: J13.22, J14.22
unnamed: J13.23, J14.23
unnamed: J13.24, J14.24
unnamed: J13.25, J14.25
unnamed: J13.26, J14.26
unnamed: J13.27, J14.27
unnamed: J13.28, J14.28
unnamed: J13.29, J14.29
unnamed: J13.30, J14.30
unnamed: J13.31, J14.31
unnamed: J13.32, J14.32
unnamed: J13.33, J14.33
unnamed: J13.34, J14.34
unnamed: J13.35, J14.35
unnamed: J13.36, J14.36
unnamed: J13.37, J14.37
unnamed: J13.38, J14.38
unnamed: J15.1, J16.1
unnamed: J15.2, J16.2
unnamed: J15.3, J16.3
unnamed: J15.4, J16.4
unnamed: J15.5, J16.5
unnamed: J15.6, J16.6
unnamed: J15.7, J16.7
unnamed: J15.8, J16.8
unnamed: J15.9, J16.9
unnamed: J15.10, J16.10
unnamed: J15.11, J16.11
unnamed: J15.12, J16.12
unnamed: J15.13, J16.13
unnamed: J15.14, J16.14
unnamed: J15.15, J16.15
unnamed: J15.16, J16.16
unnamed: J15.23, J16.23
unnamed: J15.24, J16.24
unnamed: J15.25, J16.25
unnamed: J15.26, J16.26
unnamed: J15.27, J16.27
unnamed: J15.28, J16.28
unnamed: J15.29, J16.29
unnamed: J15.30, J16.30
unnamed: J15.31, J16.31
unnamed: J15.32, J16.32
unnamed: J15.33, J16.33
unnamed: J15.34, J16.34
unnamed: J15.35, J16.35
unnamed: J15.36, J16.36
unnamed: J15.37, J16.37
unnamed: J15.38, J16.38
unnamed: J17.1, J18.1
unnamed: J17.2, J18.2
unnamed: J17.3, J18.3
unnamed: J17.4, J18.4
unnamed: J17.5, J18.5
unnamed: J17.6, J18.6
unnamed: J17.7, J18.7
unnamed: J17.8, J18.8
unnamed: J17.9, J18.9
unnamed: J17.10, J18.10
unnamed: J17.11, J18.11
unnamed: J17.12, J18.12
unnamed: J17.13, J18.13
unnamed: J17.14, J18.14
unnamed: J17.15, J18.15
unnamed: J17.16, J18.16
unnamed: J17.17, J18.17
unnamed: J17.18, J18.18
unnamed: J17.19, J18.19
unnamed: J17.20, J18.20
unnamed: J17.21, J18.21
unnamed: J17.22, J18.22
unnamed: J17.23, J18.23
unnamed: J17.24, J18.24
unnamed: J17.25, J18.25
unnamed: J17.26, J18.26
unnamed: J17.27, J18.27
unnamed: J17.28, J18.28
unnamed: J17.29, J18.29
unnamed: J17.30, J18.30
unnamed: J17.31, J18.31
unnamed: J17.32, J18.32
unnamed: J17.33, J18.33
unnamed: J17.34, J18.34
unnamed: J17.35, J18.35
unnamed: J17.36, J18.36
unnamed: J17.37, J18.37
unnamed: J17.38, J18.38
unnamed: J19.7, J20.7
unnamed: J19.8, J20.8
unnamed: J19.9, J20.9
unnamed: J19.10, J20.10
unnamed: J19.11, J20.11
unnamed: J19.12, J20.12
unnamed: J19.13, J20.13
unnamed: J19.14, J20.14
unnamed: J19.15, J20.15
unnamed: J19.16, J20.16

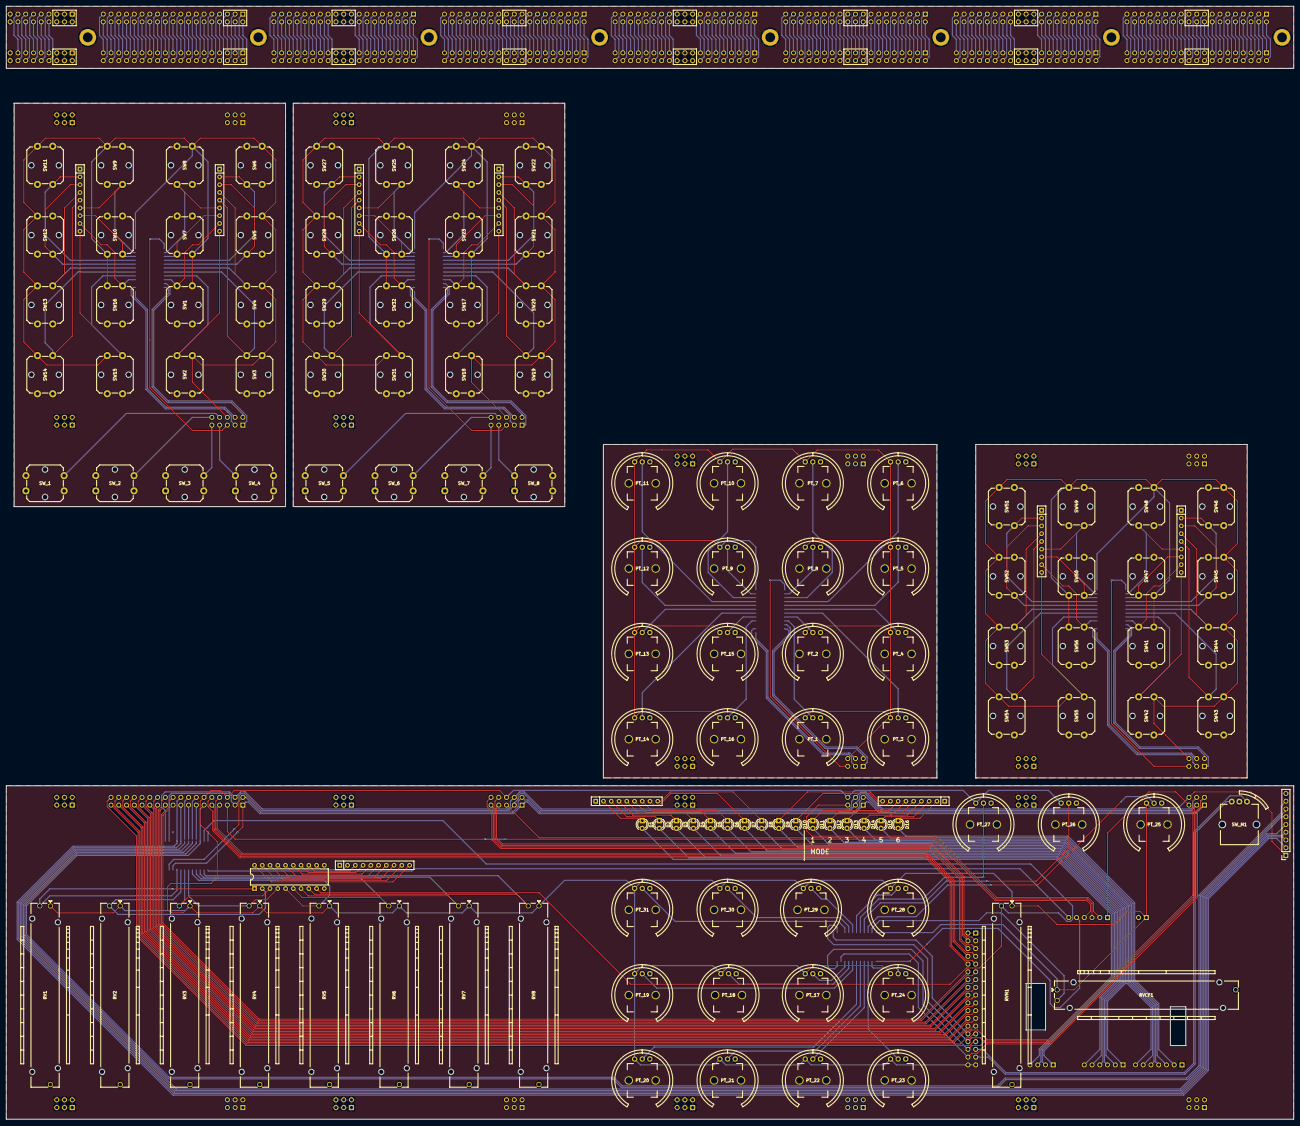
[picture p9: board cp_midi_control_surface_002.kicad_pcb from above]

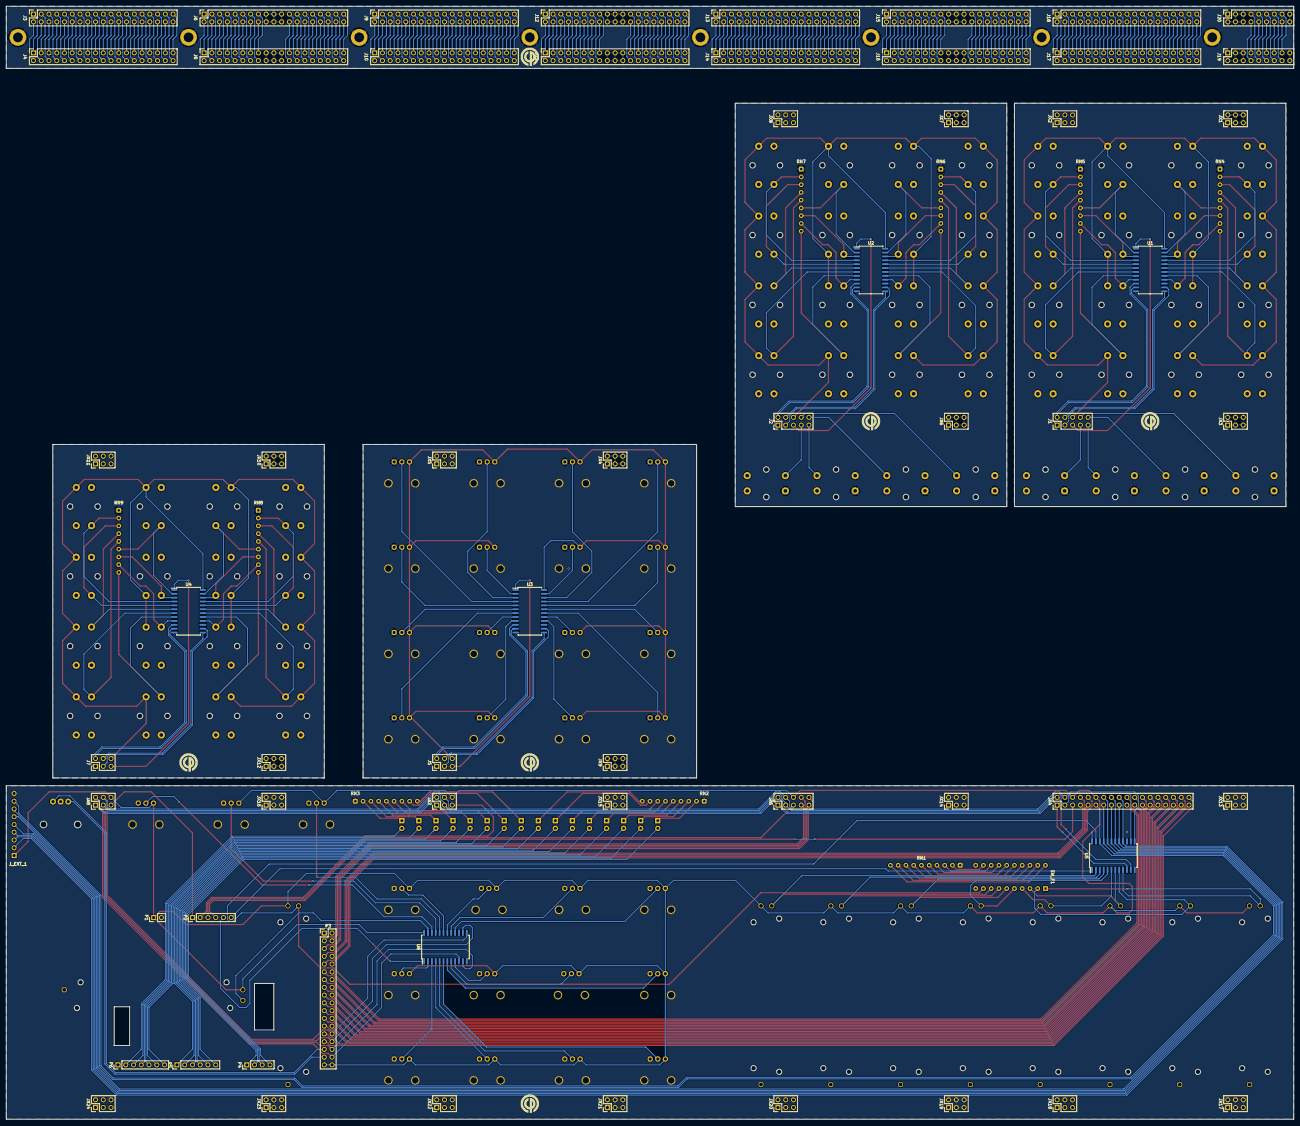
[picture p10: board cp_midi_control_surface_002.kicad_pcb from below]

Board: 2 copper layers, 421.6 x 364.5 mm, 198 parts (68 on the bottom side), 463 nets.

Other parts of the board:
P8, P9, P11, P12, P13: Guide; Mounting_Hole_M3_Target_Only

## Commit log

2019-02-19 Transfer of schematic from 002.0
    [Channel Button Strip.sch, Clip Block Left.sch, Clip Block Right.sch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]
2019-02-19 Initial potentiometer layout
    [cp_midi_control_surface_002.kicad_pcb]
2019-02-20 More initial layout
    [cp_midi_control_surface_002.kicad_pcb]
2019-02-20 Further initial placement
    [cp_midi_control_surface_002.kicad_pcb]
2019-02-20 All panel components placed
    [cp_midi_control_surface_002.kicad_pcb]
2019-02-20 Beginning button connections
    Beginning running traces to the button blocks modified schematic to ensure minimum trace length, rotate buttons to achieve this.
    [Clip Block Left.sch, VCV Button Block.sch, cp_midi_control_surface_002.kicad_pcb]
2019-02-21 Further work on the separate boards
    [Channel Button Strip.sch, Clip Block Left.sch, Clip Block Right.sch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]
2019-02-21 Further connections
    [cp_midi_control_surface_002.kicad_pcb]
2019-02-22 Connected Faders 1-8
    [cp_midi_control_surface_002.kicad_pcb]
2019-02-22 First of changes due to different software
    Moving and analogue inputs, correcting for placement of multiplexer pads.
    [cp_midi_control_surface_002.kicad_pcb, cp_midi_control_surface_002.sch]
2019-02-22 Sub boards completed
    [Channel Button Strip.sch, Clip Block Left.sch, Clip Block Right.sch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]
2019-02-23 Tidy schematic / renumber components / complete daughter boards
    [Channel Button Strip.sch, Clip Block Left.sch, Clip Block Right.sch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]
2019-02-23 Add copper fill to LED board
    [cp_midi_control_surface_002.kicad_pcb]
2019-02-24 Moved connection to crossfader to ease pin assignment on multiplexer
    [Lower_Pots.sch]
2019-02-25 Redesign of upper boards
    Added bussed resistors following Igor's correction to the schematic + tidied schematic.
    [Clip Block Left.sch, Clip Block Right.sch, Lower_Pots.sch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]
2019-02-25 Further traces added and reassigned duaghter board connection
    [cp_midi_control_surface_002.kicad_pcb, cp_midi_control_surface_002.sch]
2019-02-26 Connections complete
    All traces mapped and DRC passed apart from interboard errors - should look into fixing those.
    [cp_midi_control_surface_002.kicad_pcb, cp_midi_control_surface_002.sch]
2019-02-27 Cleaning up and rerouting traces
    [cp_midi_control_surface_002.kicad_pcb, faders.sch]
2019-02-27 Revert "Cleaning up and rerouting traces"
    This reverts commit c6a633449036ff81e758f695dc37825436db76d9.
    [cp_midi_control_surface_002.kicad_pcb, faders.sch]
2019-02-27 More rerouting
    Abortive try to reroute LEDs. Looked just as messy the other way round. Other general tidying.
    [Channel Button Strip.sch, cp_midi_control_surface_002.kicad_pcb]
2019-02-28 Added Mounting holes for alternative configuration
    Holes for swapping VCV Buttons for pots
    [cp_midi_control_surface_002.kicad_pcb]
2019-03-02 Positioned all component references on back of boards
    [cp_midi_control_surface_002.kicad_pcb]
2019-08-06 Beginning the modular redesign
    [cp_midi_control_surface_002.kicad_pcb]
2019-08-06 Added guide lines for the new board shape
    [cp_midi_control_surface_002.kicad_pcb]
2019-08-06 Resize boards and update connector
    Resized the boards to fit the new modular height and started changing the interboard connectors
    [Clip Block Right.sch, cp_midi_control_surface_002.kicad_pcb, cp_midi_control_surface_002.sch]
2019-08-07 Added Rails to Layout
    Found a big problem that the rails are compatible with the boards being modular the way the components are currently spaced.
    Which is a little frustrating.
    [cp_midi_control_surface_002.kicad_pcb]
2019-08-09 COrrected the placement of most of the components for the modular design
    Need to finalise the Arduino placement and work out the design for possible extensions.
    [cp_midi_control_surface_002.kicad_pcb]
2019-08-18 Further cleanup and placement
    Removed all the connectors to the rails as they're irrelevant to the top boards.
    Added all the support headers.
    Need to work out the correct routing for the headers but the placement is correct.
    [Channel Button Strip.sch, Clip Block Left.sch, Clip Block Right.sch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]
2019-08-21 Forgot to update a couple of components
    [cp_midi_control_surface_002.kicad_pcb, cp_midi_control_surface_002.sch]
2019-08-21 Moved two overlapping boards out of the way for clarity and cleaned up folder
    [LED_display.sch, cp_midi_control_surface_002.kicad_pcb]
2019-08-21 Routing left button blocks (traces for bottom buttons TBD)
    [cp_midi_control_surface_002.kicad_pcb]
2019-08-21 Routing traces on left button block, increased GND plane coverage.
    [cp_midi_control_surface_002.kicad_pcb]
2019-08-21 Routed power to second button board
    [cp_midi_control_surface_002.kicad_pcb]
2019-08-22 All subsidiary boards complete
    [Clip Block Left.sch, VCV Button Block.sch, cp_midi_control_surface_002.kicad_pcb]
2019-08-23 Housekeeping
    Cleaned up the schematic for the subsidiary boards
    Switched 5v and Com connections to make routing easier.
    [Clip Block Left.sch, Clip Block Right.sch, VCV Button Block.sch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]
2019-08-23 LED resistors placed
    [cp_midi_control_surface_002.kicad_pcb]
2019-08-23 Minor fiddling to adjust ground plane
    [cp_midi_control_surface_002.kicad_pcb]
2019-08-23 Reordered COM contacts and added initial trace positions
    [_saved_cp_midi_control_surface_002.sch, cp_midi_control_surface_002.kicad_pcb, cp_midi_control_surface_002.sch]
2019-08-23 Reinstated extra two pins. Probably coming out again later.
    [_saved_cp_midi_control_surface_002.sch, cp_midi_control_surface_002.sch]
2019-08-23 Bugger, found an error in the S0-S3 rail
    [cp_midi_control_surface_002.kicad_pcb]
2019-08-23 Fixed S0-S3 Rail, added LEDS
    Was an error on the schematic, easily fixed without changing the traces, glad I left it before deleting them all.
    LEDs and relate resistors are in.
    [Clip Block Left.sch, Clip Block Right.sch, VCV Button Block.sch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]
2019-08-24 Added external connections / removed unused
    +18 Buttons
    + Different connections for 7 spare multiplexer slots
    - Unused Arduino pins
    [cp_midi_control_surface_002.sch, faders.sch]
2019-08-24 Nearly there. Switch placed
    [cp_midi_control_surface_002.kicad_pcb, cp_midi_control_surface_002.sch, faders.sch]
2019-08-24 Done - needs a final check and probably some decals and whatnot.
    [cp_midi_control_surface_002.kicad_pcb]
2019-08-24 Rails done, GND corrected.
    Now for checking and decals
    [Clip Block Left.sch, Clip Block Right.sch, LED_display.sch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]
2019-08-25 Changed GND plane tightness
    Changed gap between GND plane and traces to 10 mils from 20 mils - allowed me to remove almost all GND vias on the board. Slightly rerooted traces in light of this mainlt spacing them out to allow more GND coverage.
    [cp_midi_control_surface_002.kicad_pcb]
2019-08-25 General cleaning up.
    Had a cunning idea, it wasn't cunning, lost an hour.
    Did remove the final GND via on the main board.
    [cp_midi_control_surface_002.kicad_pcb]
2019-08-26 Panel Graphics and logos added
    [cp_midi_control_surface_002.kicad_pcb]
2019-08-26 Little extra fiddling
    [cp_midi_control_surface_002.kicad_pcb]
2019-10-03 Added Baseboard drill guide
    [cp_midi_control_surface_002.kicad_pcb]
2019-10-10 Delete cp_midi_control_surface_002.kicad_pcb-bak
    Unneeded and now covered by gitignore
2019-10-10 Rename files and tidy
    [16_button_block.sch, 16_pot_block.sch]
2019-10-26 Updated Schematic and changed rotary pots
    Better button symbol and flipped all rotary pots in the schematic so they've connected the right way round.
    Changed the rotary pot footprints so the graphics match the ones I'm using.
    [16_button_block.sch, 16_pot_block.sch, Clip Block Left.sch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]
2019-10-31 Updated footprints
    [cp_midi_control_surface_002.kicad_pcb]
2019-10-31 Update cp_midi_control_surface_002.kicad_pcb
    Added vias to correct GND plane
2019-11-03 Update cp_midi_control_surface_002 - Panel.kicad_pcb

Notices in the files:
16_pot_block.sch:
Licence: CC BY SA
